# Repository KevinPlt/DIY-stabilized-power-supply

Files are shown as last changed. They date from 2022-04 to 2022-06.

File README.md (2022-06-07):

# DIY-stabilized-power-supply

## Description of the projet

The aim of the project is to make a wood box in order to create a stabilized power supply from an old ATX PC power supply with a lot of accessible voltages. It is also recommended to have an adjustable power supply, so it will embed a system to do this.

## Prerequisite
### For the wood box
- MDF wood 5mm thick
- wood cleats
- 2 hinges
- 8 M3x6mm philips metal screws ([M3 kit](https://s.click.aliexpress.com/e/_9ykpjx))
- 8 M3 nuts
- 8 M3 washers
- wood screws
- clear sticky paper for the front silkscreen

### For the features
- An old ATX PC power supply (330W)
- 6 red [banana plugs](https://s.click.aliexpress.com/e/_AswMil) 
- 6 black banana plugs
- Adjustable power suply controller : [DPH 5005 with USB communication](https://s.click.aliexpress.com/e/_AbeLhP)
- 1 toggle switch ([SPDT](https://s.click.aliexpress.com/e/_Aqw6Pf))
- 1 LED (in my setup it is blue) ([LED kit](https://s.click.aliexpress.com/e/_A9tfNf))
- 1 resistor (1 kohm) ([Resistor kit](https://s.click.aliexpress.com/e/_Acxarr))
- wires

## Assembly Modeling
Made with Solidworks 2017.
In this assembly, the wood cleats are not shown.
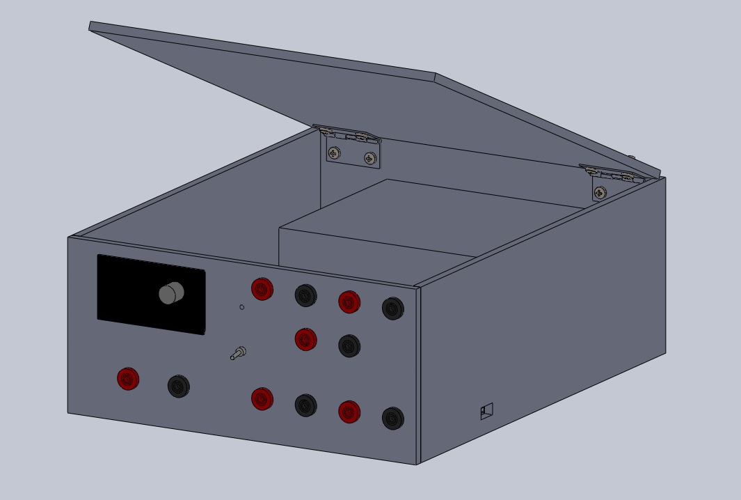
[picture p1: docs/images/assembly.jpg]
Screenshot of the assembly in isometric view

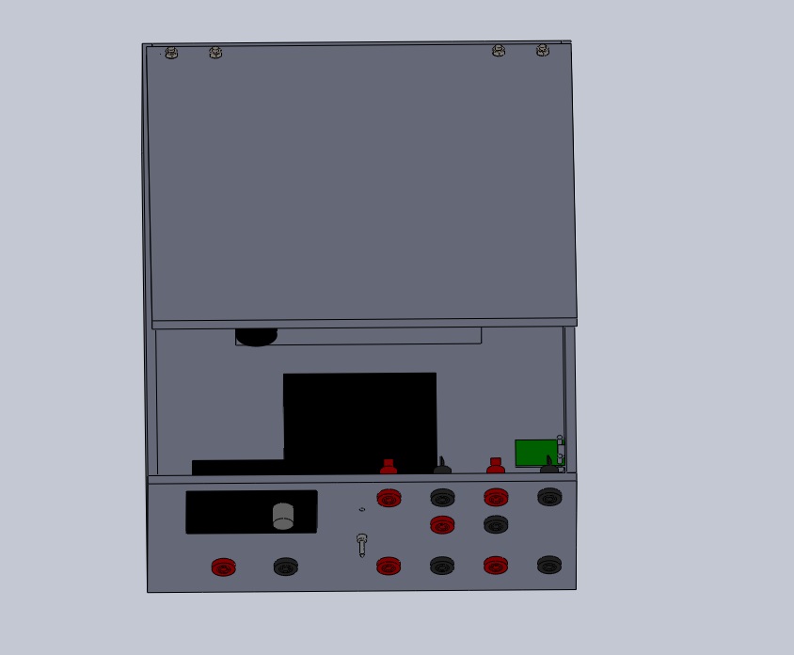
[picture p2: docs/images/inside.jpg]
Screenshot of the inside of the assembly


## Mechanism
- Edited with Solidworks 2017
- Exported from Solidworks to DXF each part of the box
- Exported from [Inkscape](https://github.com/inkscape/inkscape) to SVG each part
- Computed toolpath (gcode) with makercam software (makercam.swf) by defining every operations (this software takes in input only SVG files and it is deprecated)
- Execute gcode for each part with [bCNC](https://github.com/vlachoudis/bCNC) with Shapeoko 3

## Final Assembly
Dimensions of the wood box : (WidthxHeightxDepth) 261x124x330mm

Wood box isometric photo
Wood bow front photo
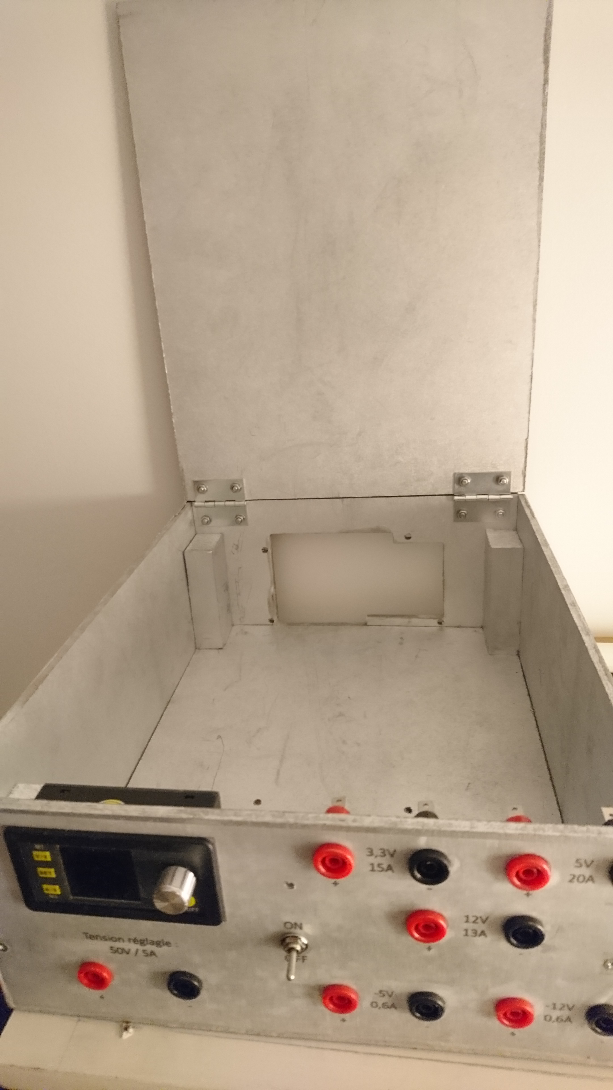
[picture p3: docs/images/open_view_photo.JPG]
Wood box open photo


## Connections into the wood box

This is a schematic diagram. It shows the idea how it is connected inside the wood box.

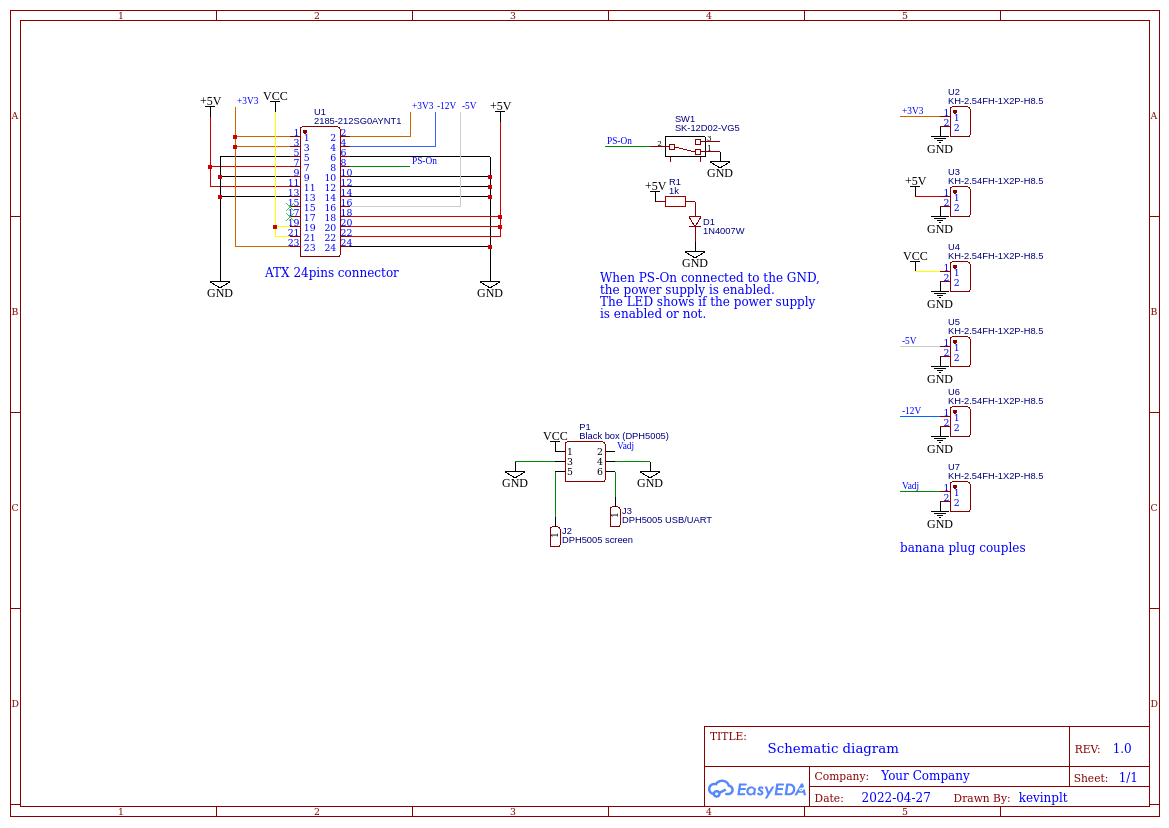
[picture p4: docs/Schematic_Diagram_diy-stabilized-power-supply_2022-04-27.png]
Schematic diagram


## Thanks
To [Vasilis Vlachoudis](https://github.com/vlachoudis) having created the bCNC project.

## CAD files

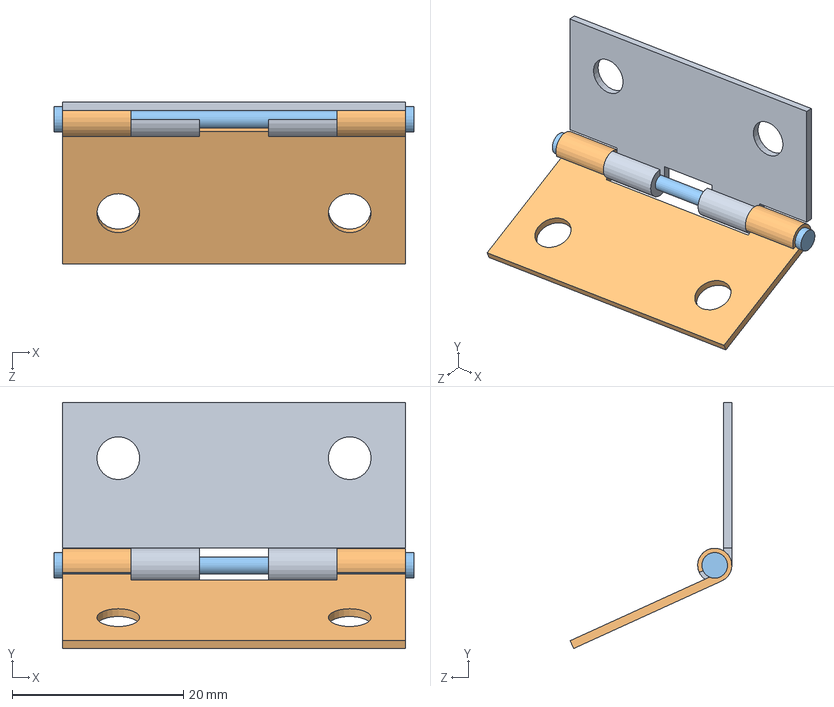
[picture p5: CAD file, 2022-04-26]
Solidworks_Sources/hinge/Hinge.SLDASM
42.0 x 28.7 x 18.9 mm
charniere part 1
charniere part 2
tige

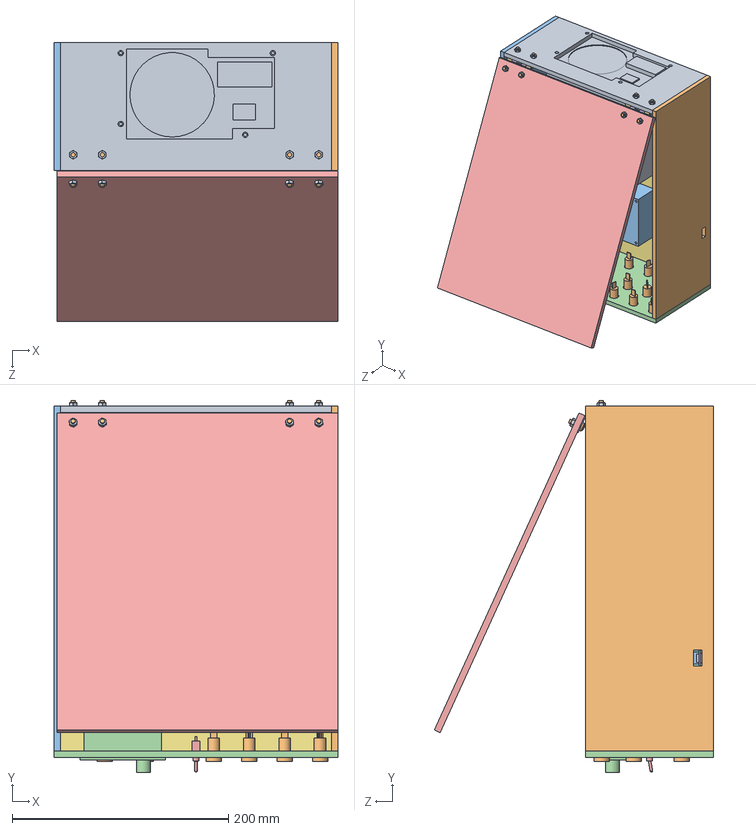
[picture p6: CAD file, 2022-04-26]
Solidworks_Sources/DIYStabilizedPowerSupply.SLDASM
262.0 x 343.7 x 258.2 mm
Alim_ATX
banana_plug x 12
mother_board_DPX
screen_DPX
switch
uart
bottom_side
entretoise M3x6 x 2
back_side
right_side
left_side
front_side
top_side
charniere part 1 x 2
charniere part 2 x 2
tige x 2
hex nut style 1 gradeab_iso x 8
pan head cross recess screw_iso x 8

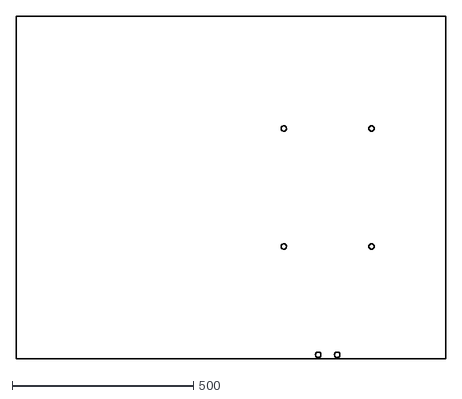
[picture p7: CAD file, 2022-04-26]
DXF/bottom_side.DXF
1183.0 x 944.9

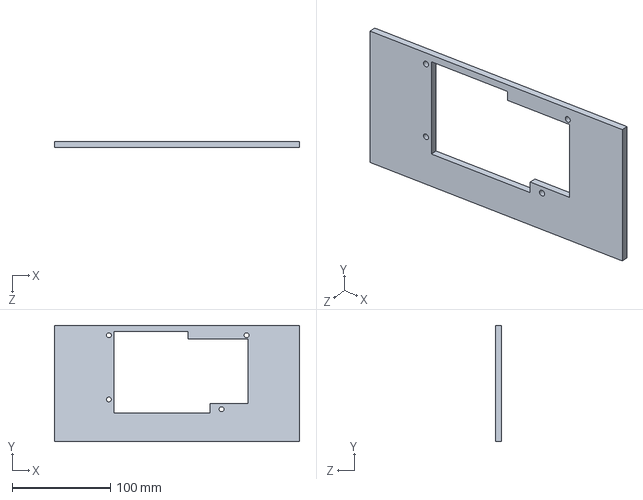
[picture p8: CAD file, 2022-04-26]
Solidworks_Sources/back_side.SLDPRT
250.0 x 118.4 x 6.00 mm

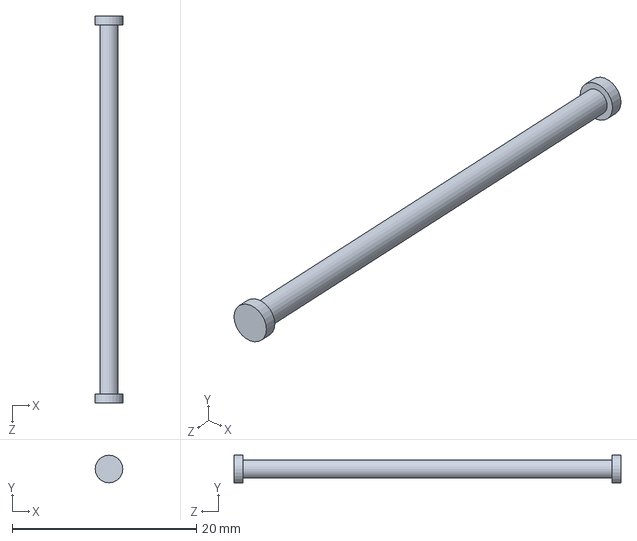
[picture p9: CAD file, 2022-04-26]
Solidworks_Sources/hinge/stem.SLDPRT
3.00 x 3.00 x 42.0 mm

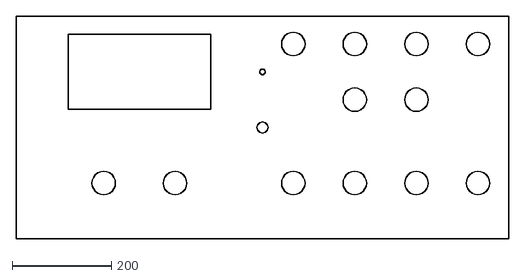
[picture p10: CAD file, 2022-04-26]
DXF/front_side.DXF
990.2 x 447.6

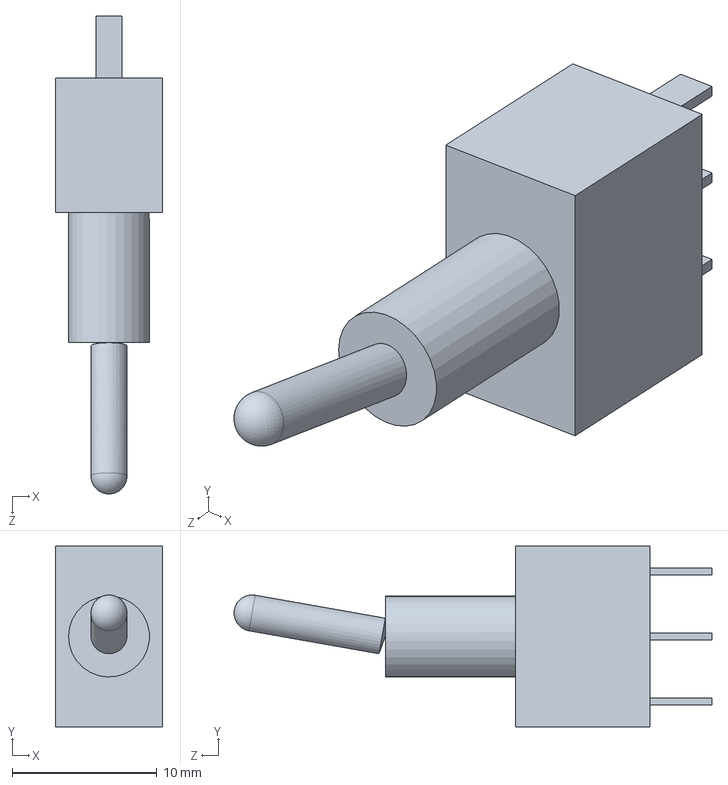
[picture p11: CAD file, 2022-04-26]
Solidworks_Sources/switch.SLDPRT
7.40 x 12.5 x 33.1 mm

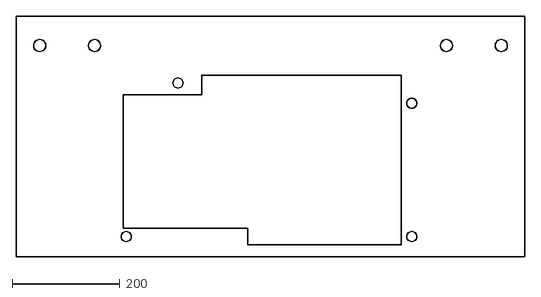
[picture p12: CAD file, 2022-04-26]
DXF/back_side.DXF
944.9 x 447.6

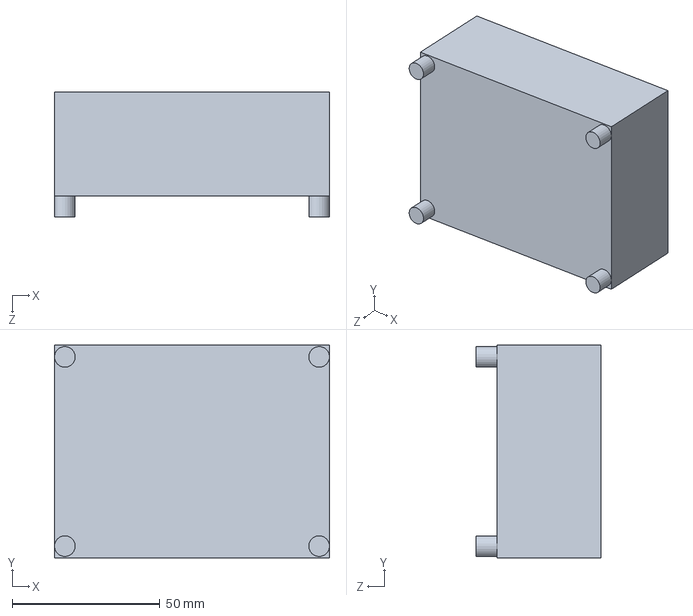
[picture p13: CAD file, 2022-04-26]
Solidworks_Sources/DPHMotherboard.SLDPRT
93.0 x 72.0 x 42.2 mm

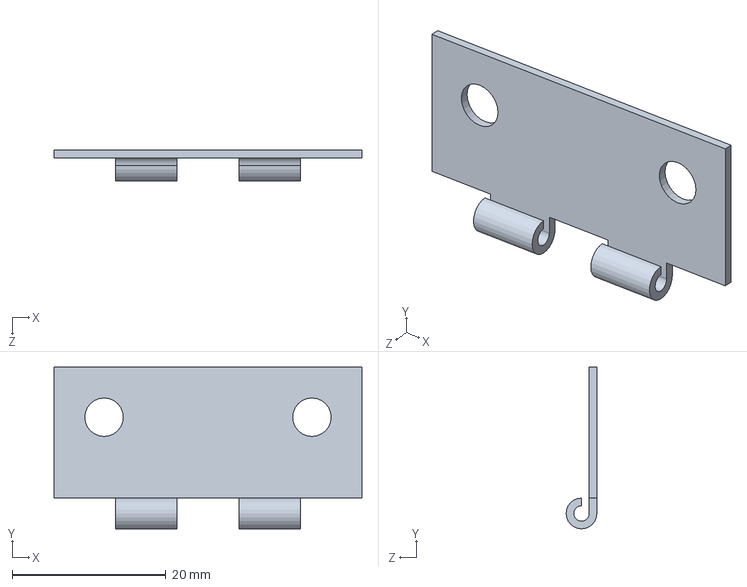
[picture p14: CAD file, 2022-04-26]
Solidworks_Sources/hinge/hingePart1.SLDPRT
40.0 x 21.0 x 4.00 mm

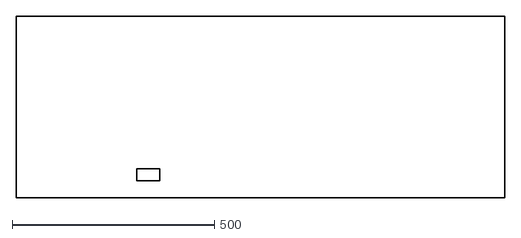
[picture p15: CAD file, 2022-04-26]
DXF/right_side.DXF
1205.7 x 447.6

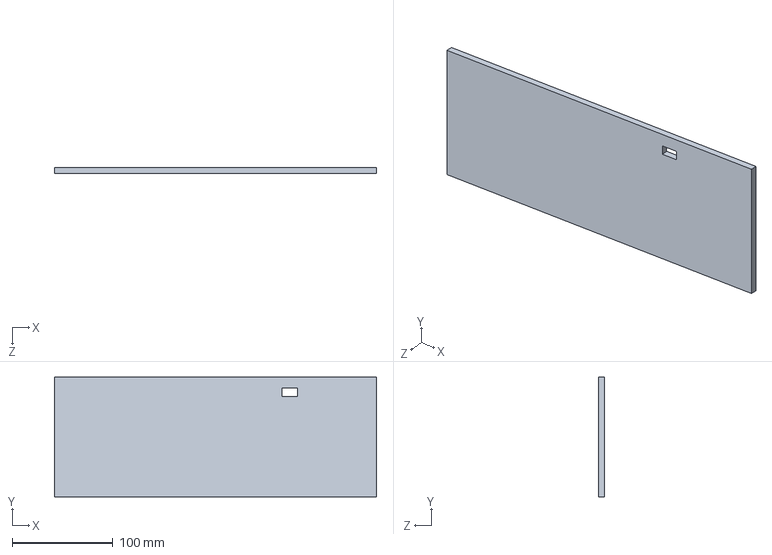
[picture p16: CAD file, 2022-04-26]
Solidworks_Sources/right_side.SLDPRT
319.0 x 118.4 x 6.00 mm

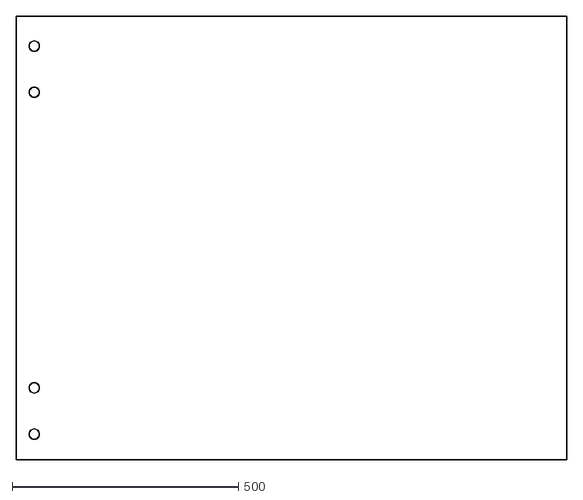
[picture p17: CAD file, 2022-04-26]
DXF/top_side.DXF
1217.0 x 981.1

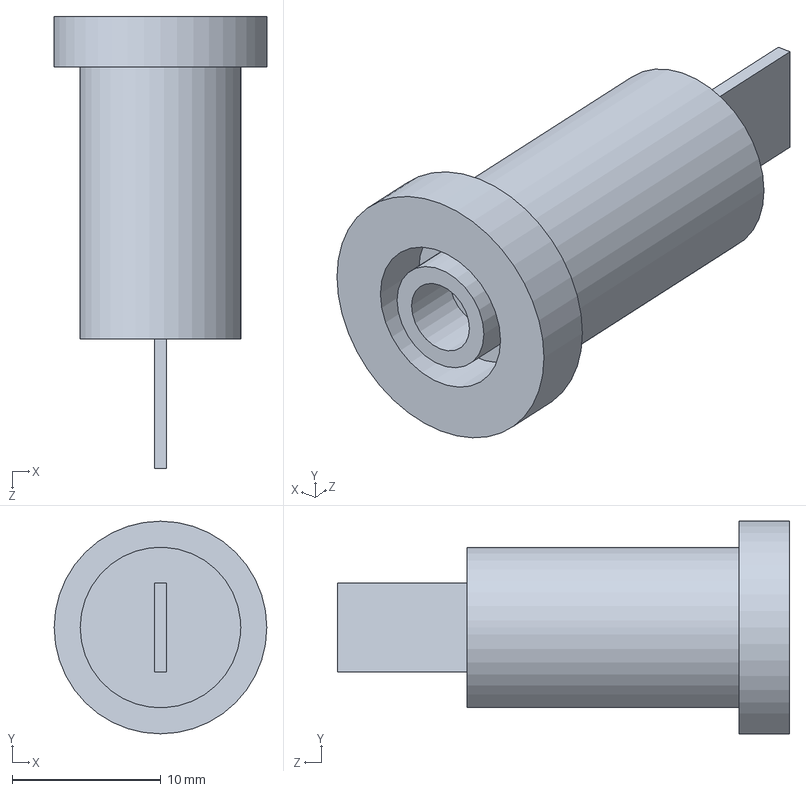
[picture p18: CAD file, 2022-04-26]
Solidworks_Sources/banana_plug.SLDPRT
14.3 x 14.3 x 30.4 mm

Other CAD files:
Solidworks_Sources/hinge/hingePart2.SLDPRT
DXF/left_side.DXF
Solidworks_Sources/DPX_UART.SLDPRT
Solidworks_Sources/ATXPowerSupply.SLDPRT
Solidworks_Sources/DPHScreen.SLDPRT
Solidworks_Sources/M3x6_spacer.SLDPRT
Solidworks_Sources/bottom_side.SLDPRT
Solidworks_Sources/front_side.SLDPRT
Solidworks_Sources/left_side.SLDPRT
Solidworks_Sources/top_side.SLDPRT

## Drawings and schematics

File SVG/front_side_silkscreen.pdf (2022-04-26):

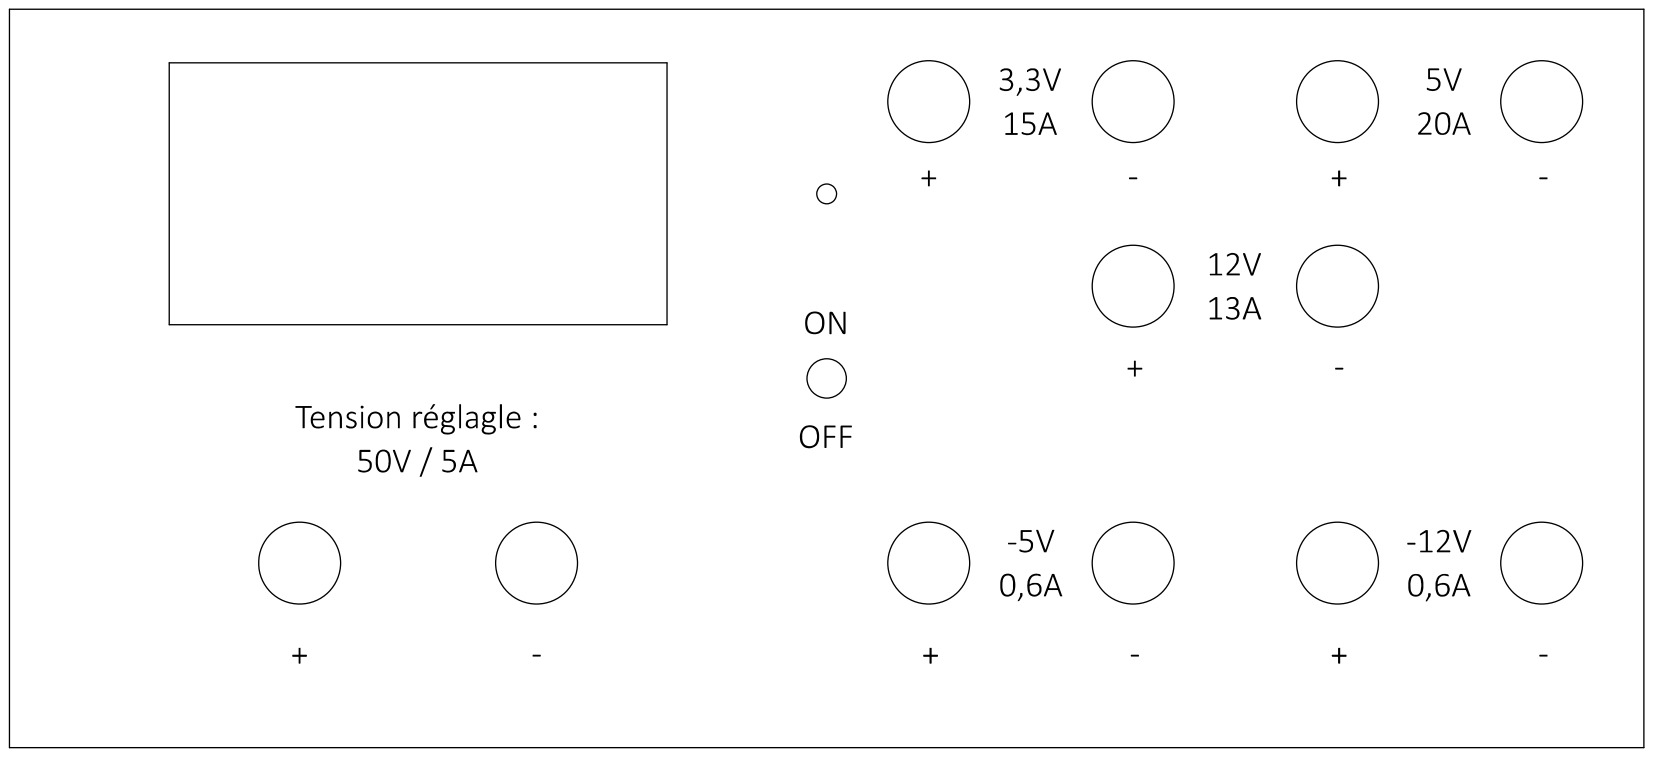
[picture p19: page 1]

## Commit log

2022-04-26 Add Soldworks source files for the box with all components
    [ATXPowerSupply.SLDPRT, DIYStabilizedPowerSupply.SLDASM, DPHMotherboard.SLDPRT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]
2022-04-26 Adding dxf folder containing dxf files for each part (output of solidworks)
    [back_side.DXF, bottom_side.DXF, front_side.DXF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]
2022-04-27 Added schematic diagram to readme
2022-05-27 Adding screenshot of the modelisation of the assembly
2022-05-27 Editing readme to insert screenshots of the assembly
2022-06-03 Editing readme to insert final photo of the wood box
